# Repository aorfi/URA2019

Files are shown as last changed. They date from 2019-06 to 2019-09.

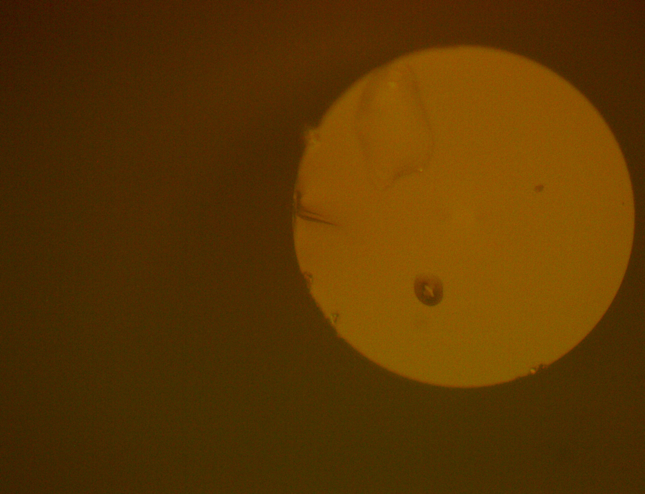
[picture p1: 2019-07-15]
Photos/CameraTest1-2.jpg

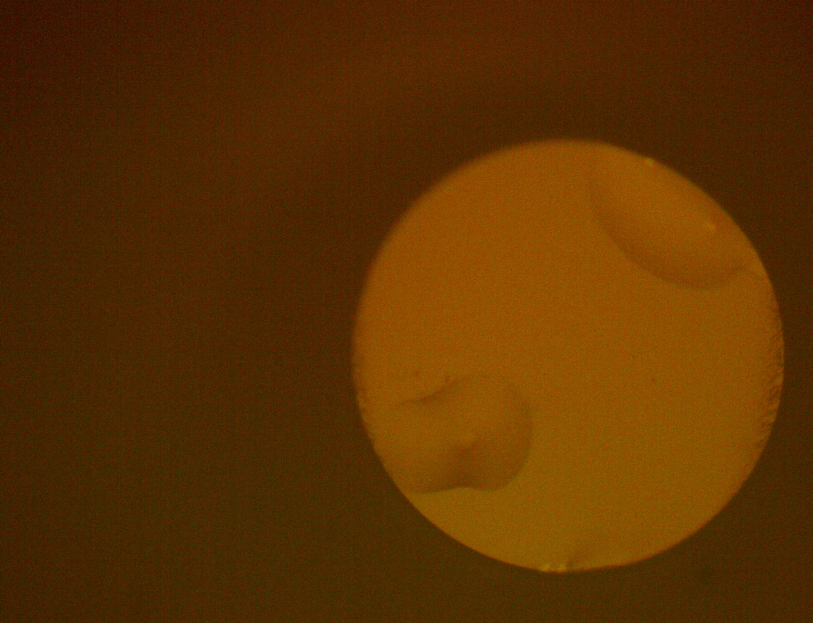
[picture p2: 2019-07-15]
Photos/CameraTest4-1.jpg

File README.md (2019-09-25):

# Undergraduate Research Assistant 

Working in Professor Bajcsy's Nano-Photonics and Quantum Optics Laboratory on the manufacturing of fiber based Fabry Perot cavities. 

## Assemblies Overview
This gives a brief explanation of each of the assemblies tested.  
### PolarizationMethod
This assembly was used to test the butt-coupling method of UV resin transfer. There were many iterations of this design, this assembly currently represents the final iteration, which was manufactured at the end of the work term.

### Camera Setup
This two camera setup was used to see the fiber alignment for the butt-coupling technique. It uses a rack and pinion design to vary the distance of the camera to the sample so that the focus can be easily found. There also exists a configuration with fixed distances, which has better structural integrity.

### RotatingCamera
This is a single USB camera mount with variable rotation. It can be used to view the reflection of the fiber in order to insure the fiber is perpendicular to the mirror. 

### ChipHolder
This simple assembly is used as a mounting feature for the fiber holder chip. It can be used to mount both the horizontal optical post as well as to sit stably on the translation stage.

## Parts Organization
Most parts were custom designed to be 3D printed, thus are stored in the CustomParts folder. Some of the later assemblies also are stored in this folder. The COTS folder stores the off the shelf items, most coming from [McMaster-Carr](https://www.mcmaster.com/) or [Thor Labs](https://www.thorlabs.com/index.cfm)

## Other
Various photos of test performed can be found in the photos folder. In addition, the slides for presentations are in the GroupMeetings folder.

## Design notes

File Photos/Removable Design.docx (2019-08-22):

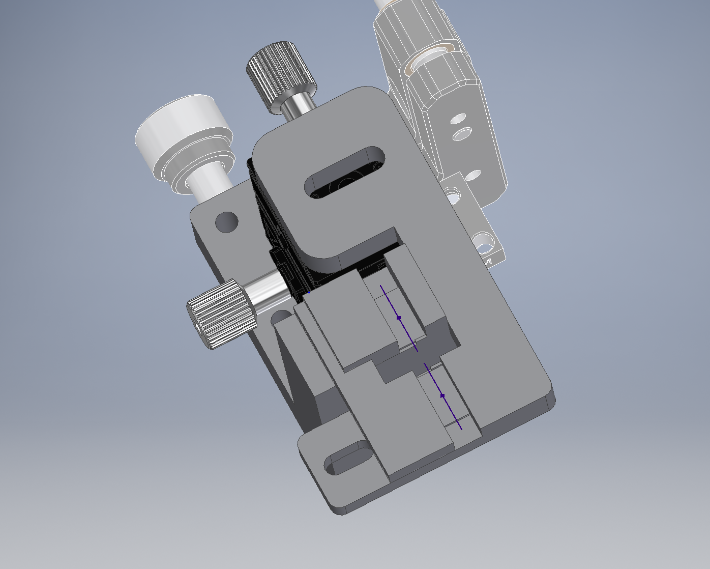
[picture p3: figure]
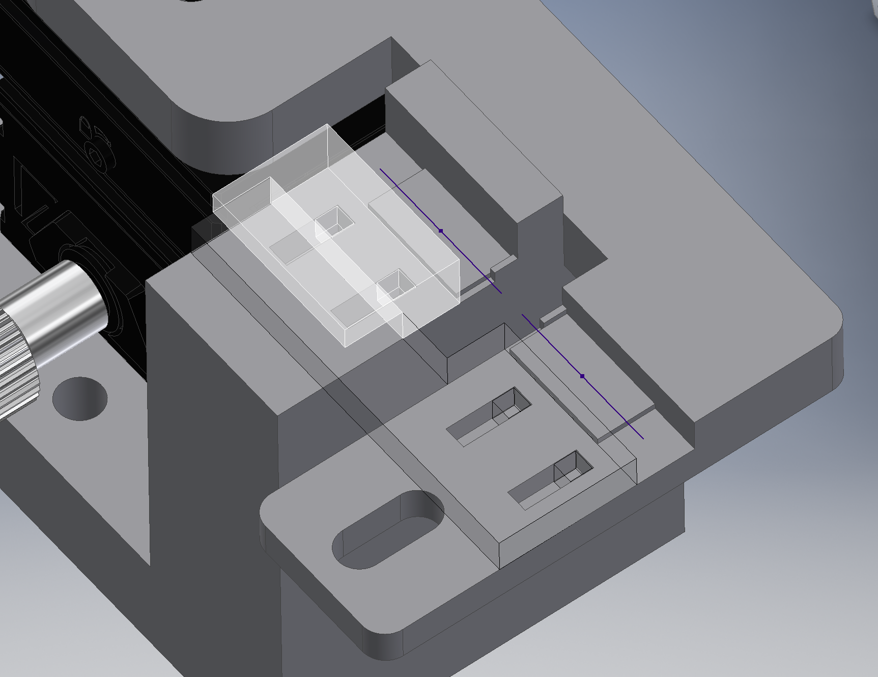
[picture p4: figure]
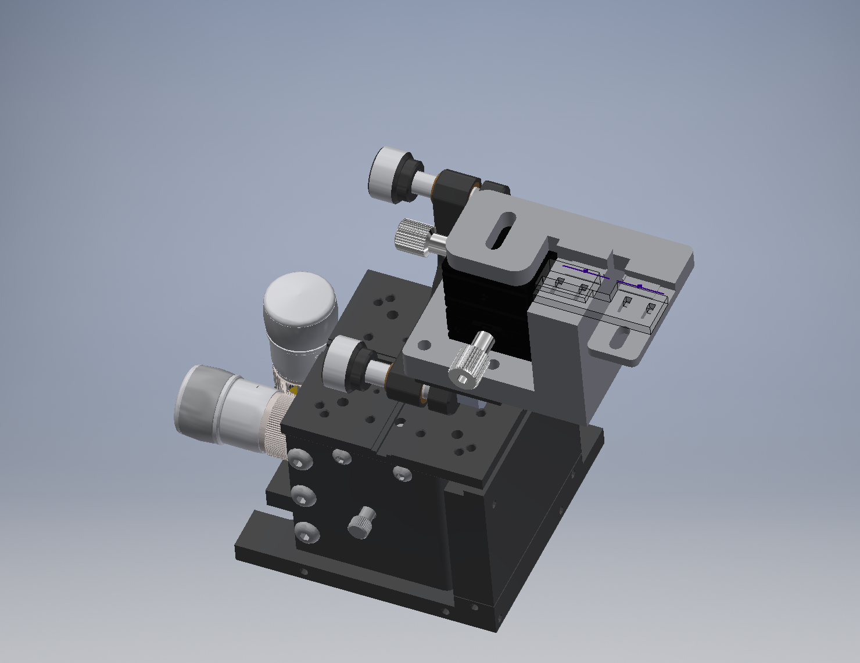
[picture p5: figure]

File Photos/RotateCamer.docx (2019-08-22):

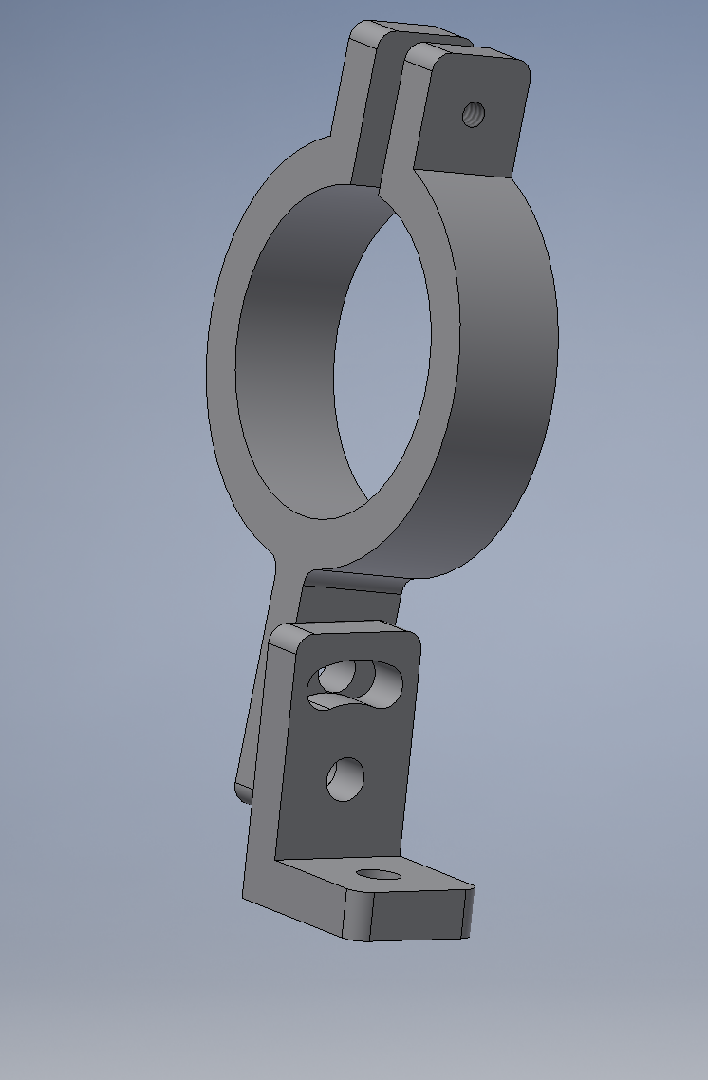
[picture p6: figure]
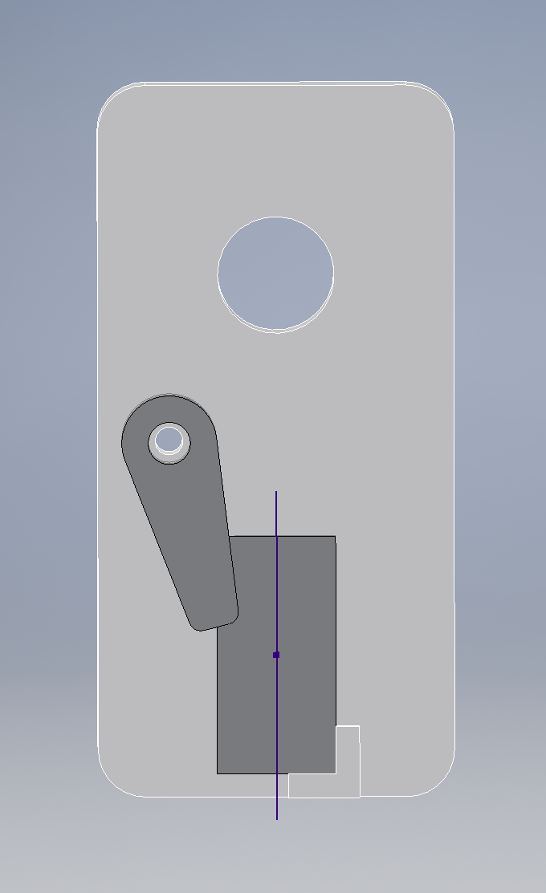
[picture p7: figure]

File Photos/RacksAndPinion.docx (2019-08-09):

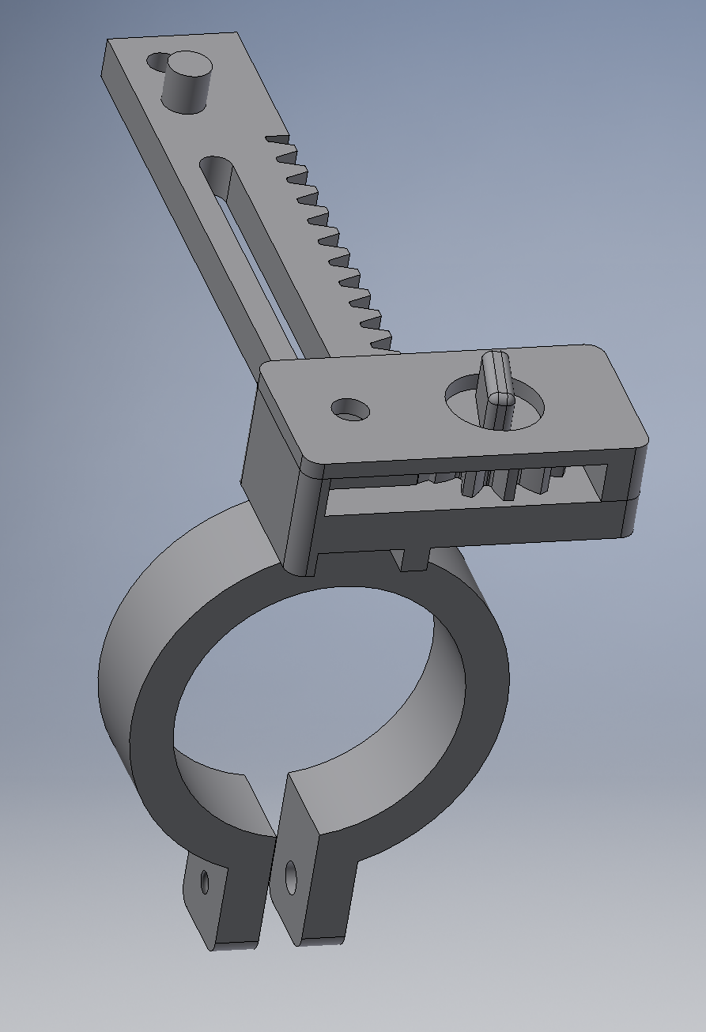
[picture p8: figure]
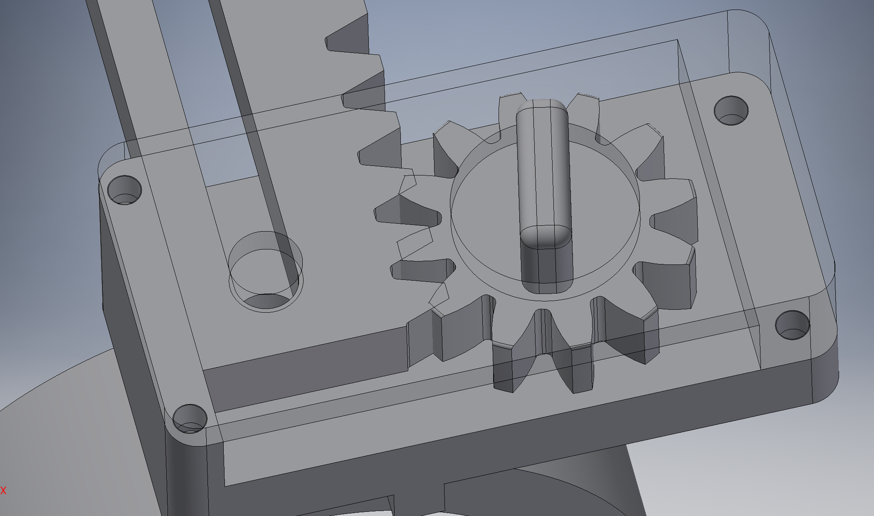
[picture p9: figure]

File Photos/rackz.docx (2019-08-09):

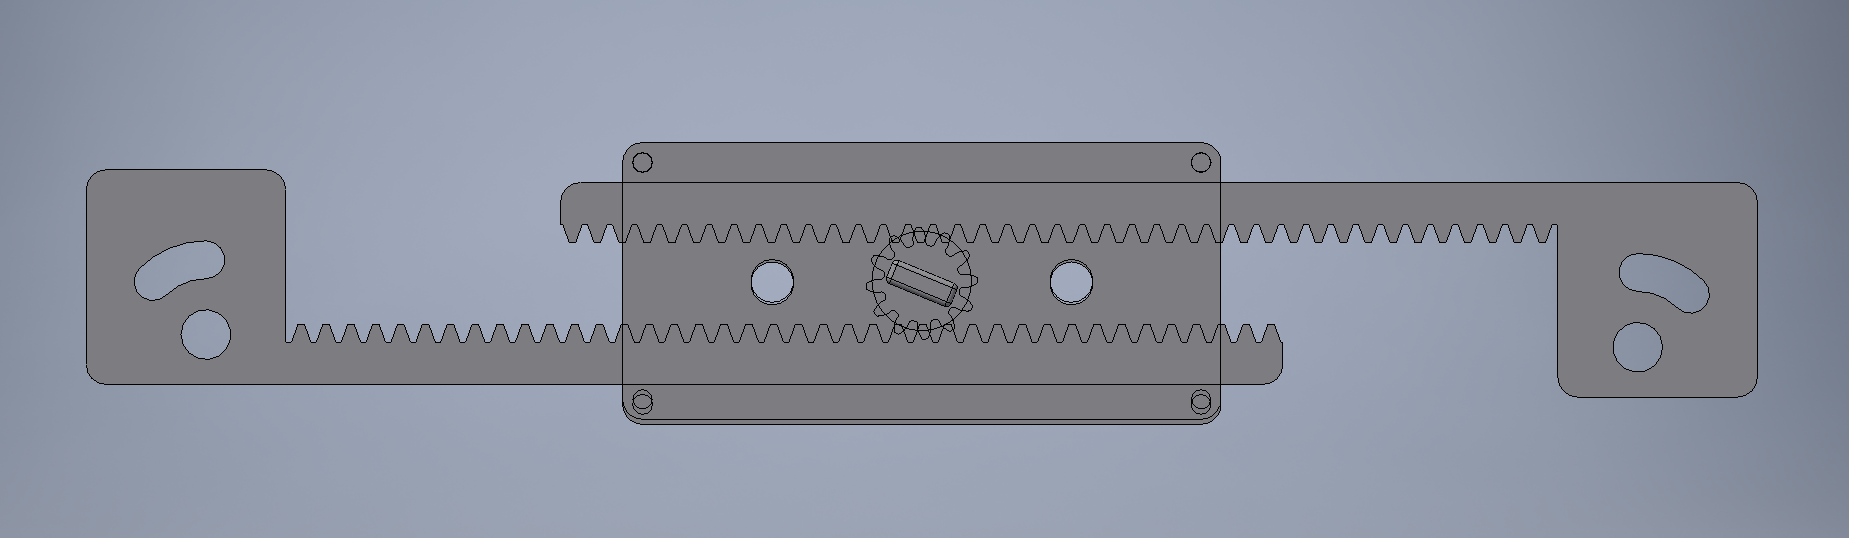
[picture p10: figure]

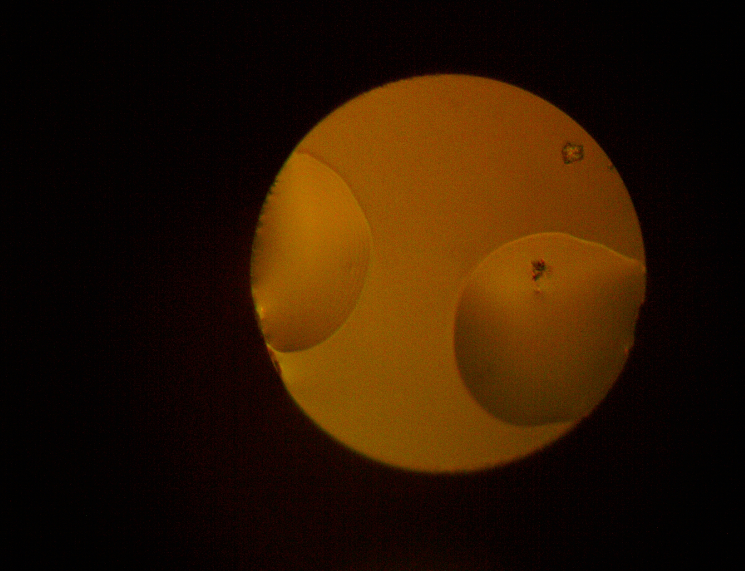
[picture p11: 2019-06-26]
Photos/RemovableDesign3-1.jpg

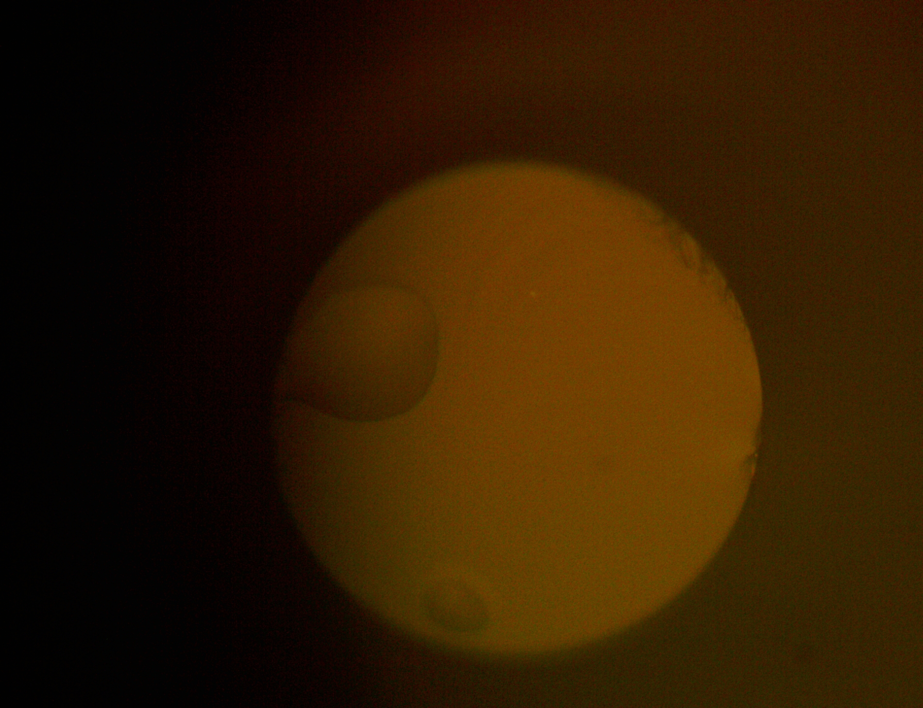
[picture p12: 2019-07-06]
Photos/RemovableDesign7-2.jpg

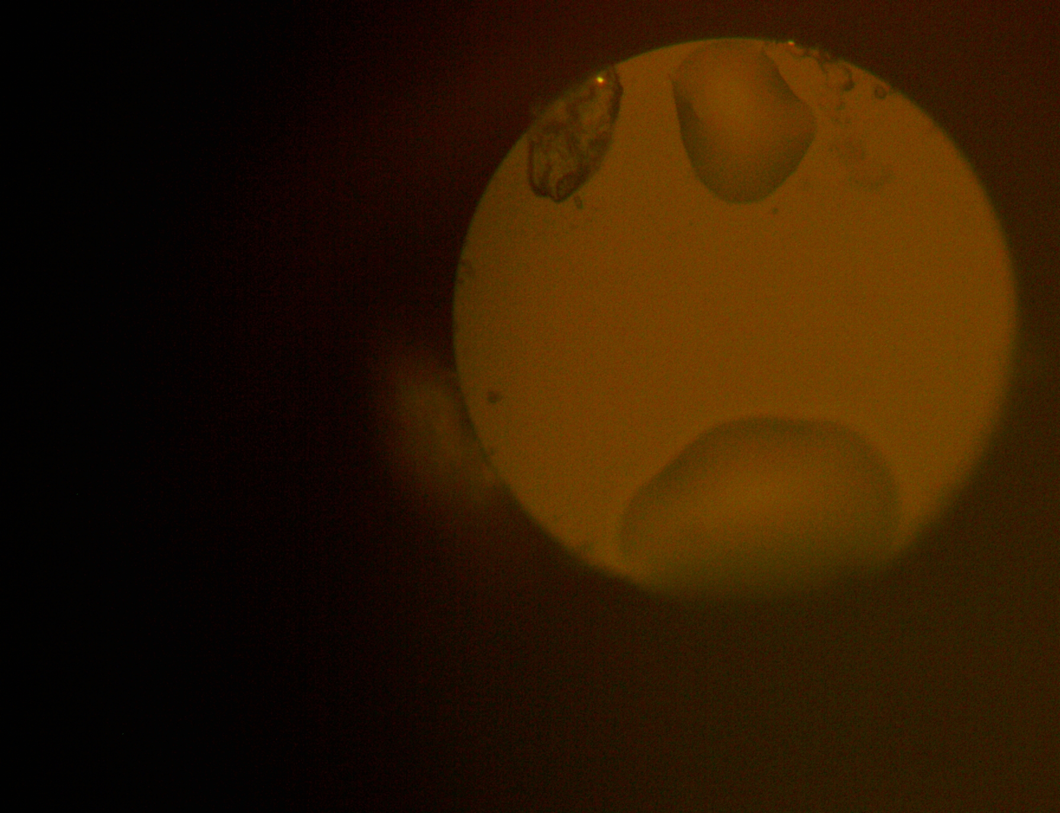
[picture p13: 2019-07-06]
Photos/RemovableDesign8-1.jpg

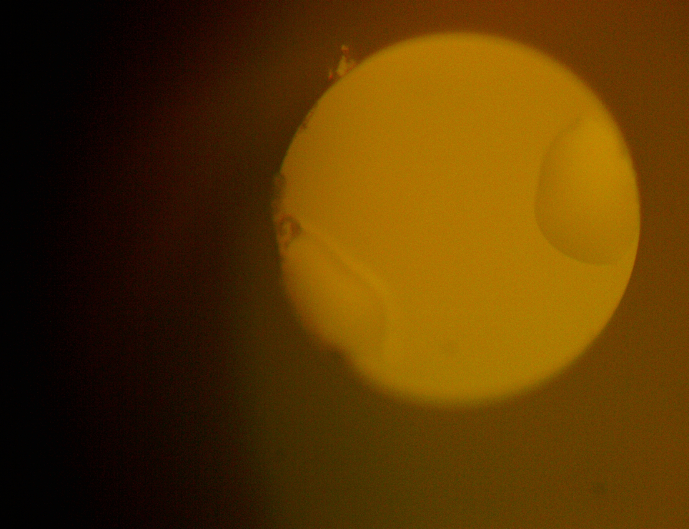
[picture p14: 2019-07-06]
Photos/RemovableDesign10-1.jpg

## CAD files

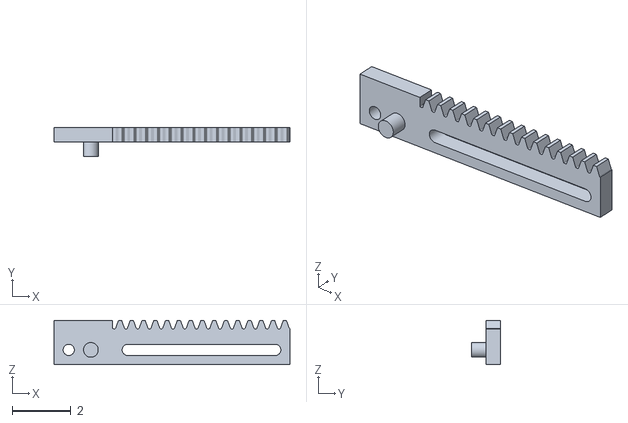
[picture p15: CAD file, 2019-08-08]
CustomParts/Rack.stl
8.00 x 1.00 x 1.50

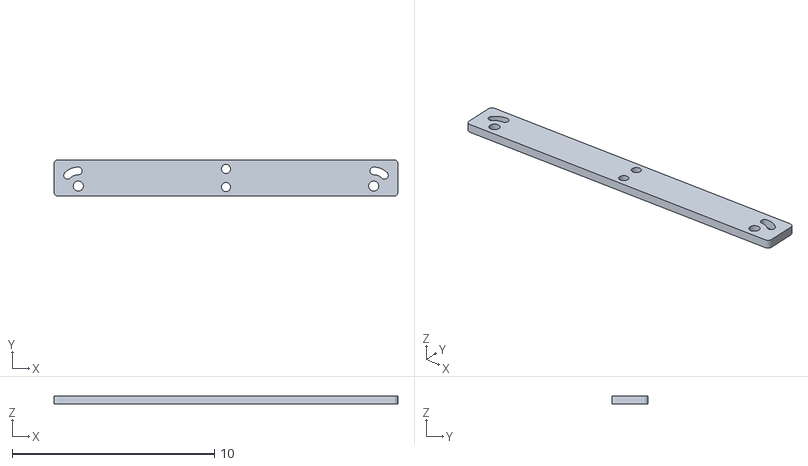
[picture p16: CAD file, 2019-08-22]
Printing/CameraBase.stl
17.0 x 1.80 x 0.4

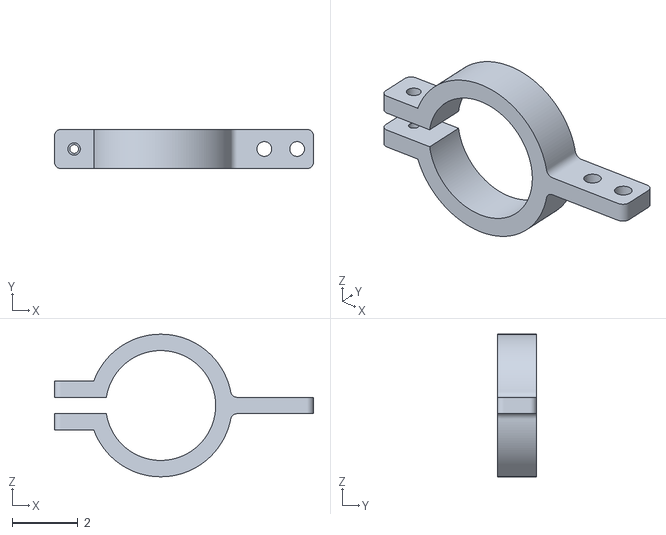
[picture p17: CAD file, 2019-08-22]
Printing/CameraClampRotate.stl
7.90 x 1.20 x 4.35

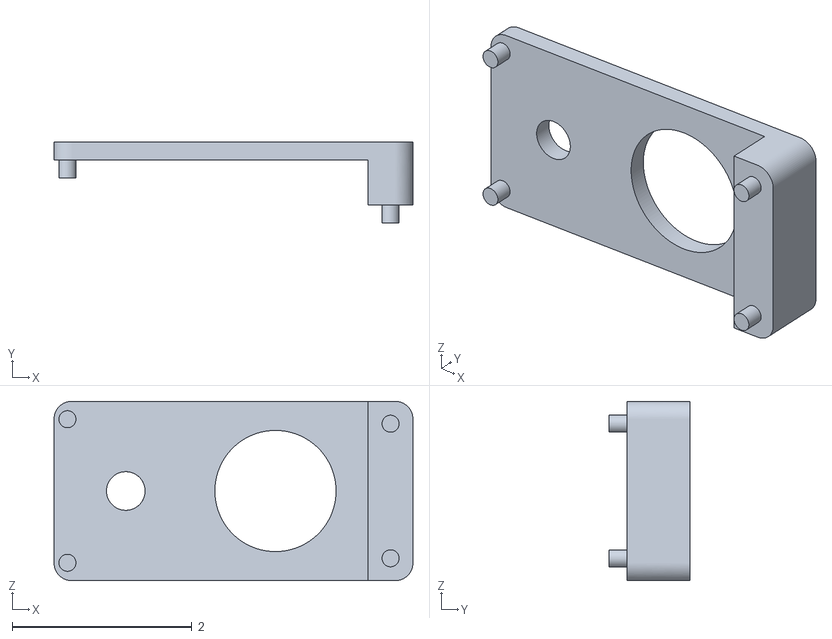
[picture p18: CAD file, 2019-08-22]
Printing/GearCover.stl
4.00 x 0.9 x 2.00

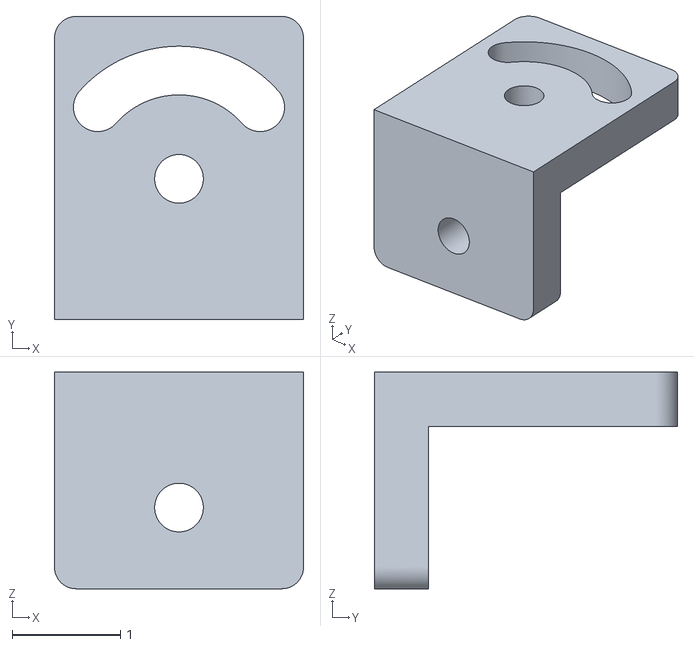
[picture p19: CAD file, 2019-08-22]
Printing/RotateLBracket.stl
2.30 x 2.80 x 2.00

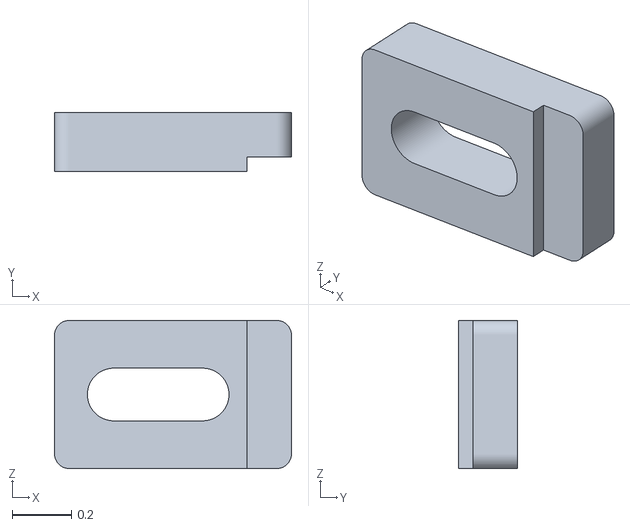
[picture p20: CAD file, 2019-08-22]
Printing/ChipClip.stl
0.8 x 0.2 x 0.5

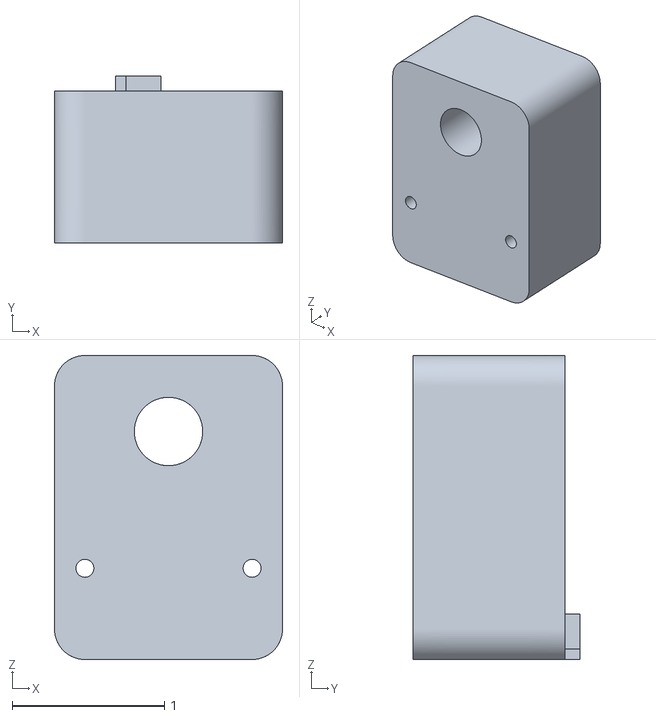
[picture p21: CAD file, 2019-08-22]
Printing/ChipHolder.stl
1.50 x 1.10 x 2.00

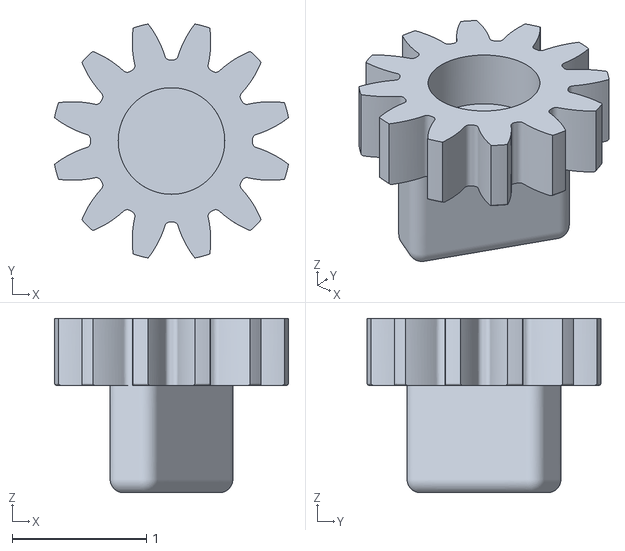
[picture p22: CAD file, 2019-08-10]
Printing/Pinion.stl
1.74 x 1.74 x 1.30

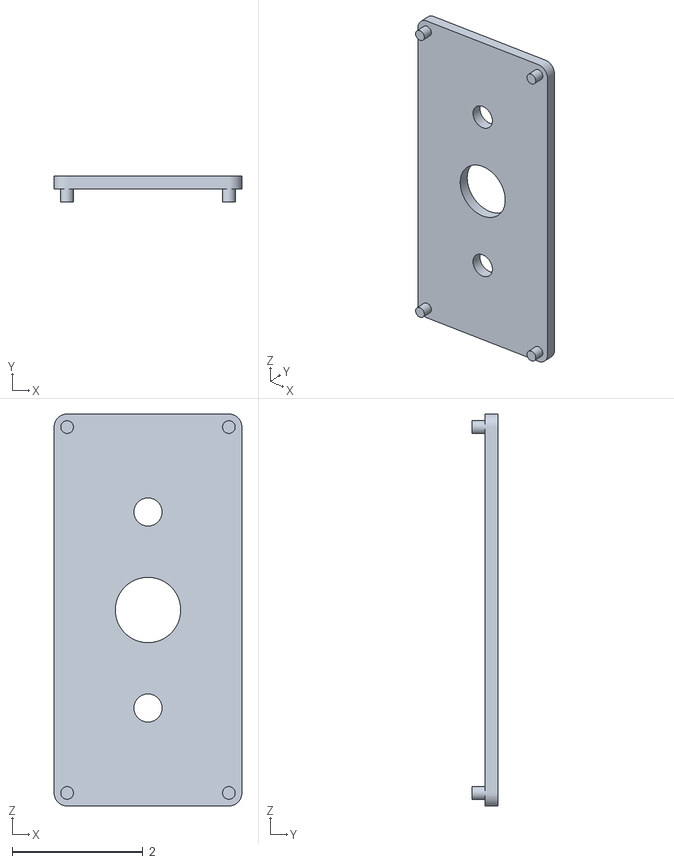
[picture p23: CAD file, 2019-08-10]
Printing/GearCoverTop.stl
2.88 x 0.4 x 6.00

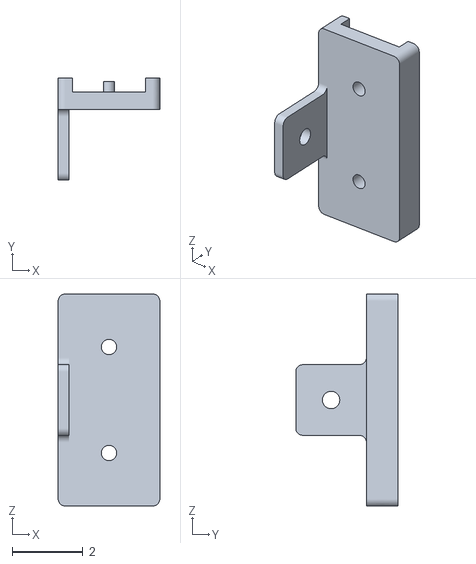
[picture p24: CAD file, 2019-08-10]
Printing/CameraLinearSupporter.stl
2.88 x 2.90 x 6.00

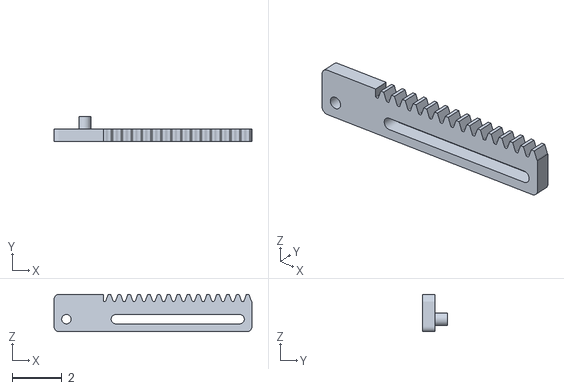
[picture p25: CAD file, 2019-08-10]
Printing/RackMirror.stl
8.00 x 1.00 x 1.50

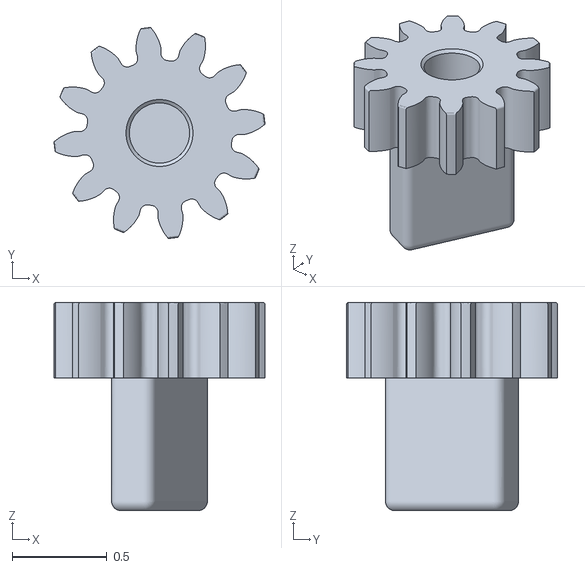
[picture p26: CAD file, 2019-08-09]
Printing/SmallPinion.stl
1.11 x 1.11 x 1.10

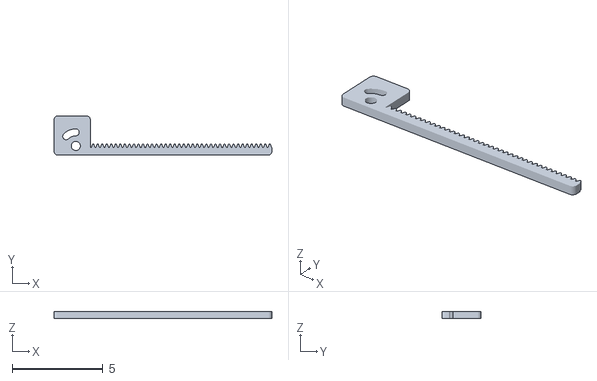
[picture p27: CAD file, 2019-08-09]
Printing/CameraBaseLeft.stl
12.0 x 2.15 x 0.4

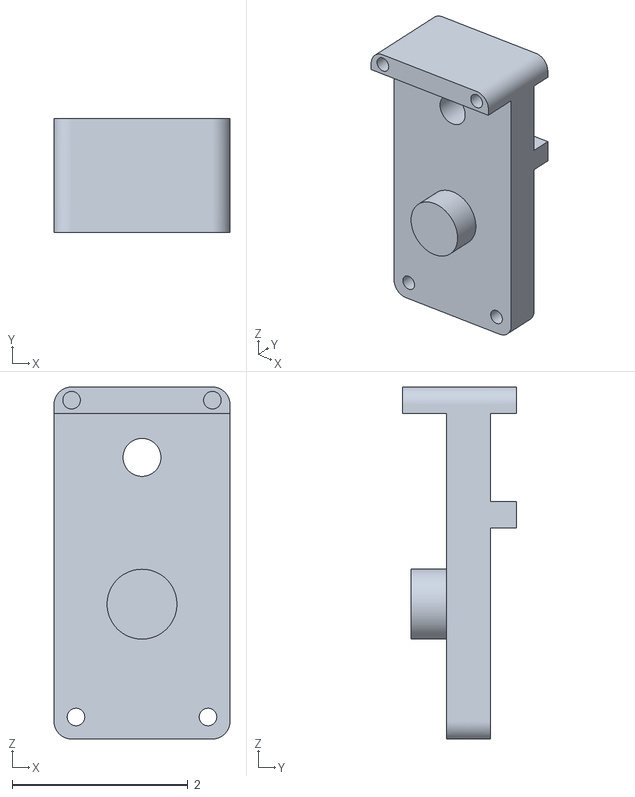
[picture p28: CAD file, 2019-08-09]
Printing/PinionHolder.stl
2.00 x 1.30 x 4.00

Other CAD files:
Printing/CameraBaseRight.stl
Printing/Nut0.375-16.stl
Printing/Pawl2.stl
Printing/PinionHolderTest.stl
COTS/BallBearing.ipt
COTS/McMaster/0.125-0.25-Shoulder91259A156.ipt
COTS/McMaster/0.125-0.3125-Shoulder91259A156.ipt
COTS/McMaster/0.125-0.375-Shoulder91259A156.ipt
COTS/McMaster/440-Nut90480A005.ipt
COTS/Newport/LinearStage-MS-125-X.ipt
COTS/ThorLabs/LinearStage-MS1S.ipt
COTS/ThorLabs/RollStage-RSP1_M.ipt
COTS/ThorLabs/YawPitchStage-KM100PM.ipt
COTS/USBCamera.ipt
CameraSetup.iam
ChipMountAssembly.iam
CustomParts/7880K140_HT-LOAD MTL GEAR--20 DEG PRESSURE ANGLE.ipt
CustomParts/AlignmentPiece.ipt
CustomParts/BaseMount.ipt
CustomParts/BearingMount.ipt
CustomParts/CameraBase.ipt
CustomParts/CameraBaseLeft.ipt
CustomParts/CameraBaseRight.ipt
CustomParts/CameraClamp.ipt
CustomParts/CameraClampRotate.ipt
CustomParts/CameraLBracket.ipt
CustomParts/CameraLinearSupporter.ipt
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

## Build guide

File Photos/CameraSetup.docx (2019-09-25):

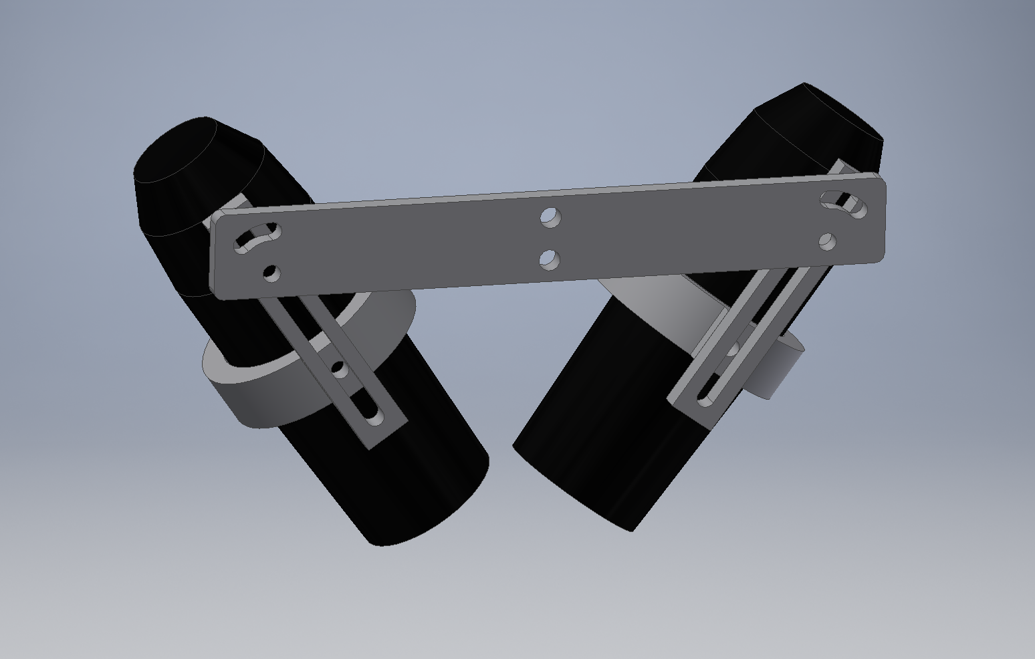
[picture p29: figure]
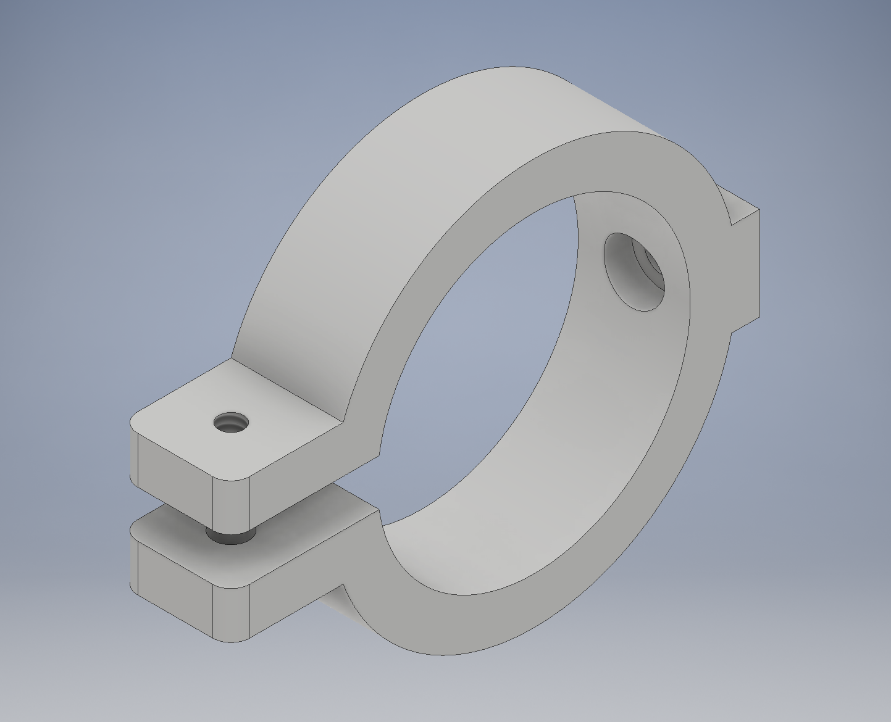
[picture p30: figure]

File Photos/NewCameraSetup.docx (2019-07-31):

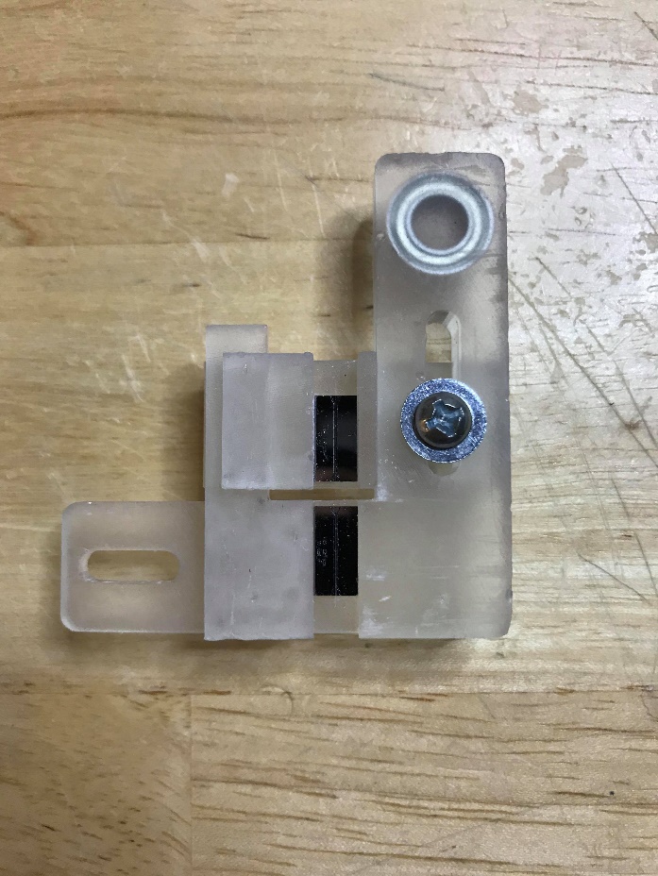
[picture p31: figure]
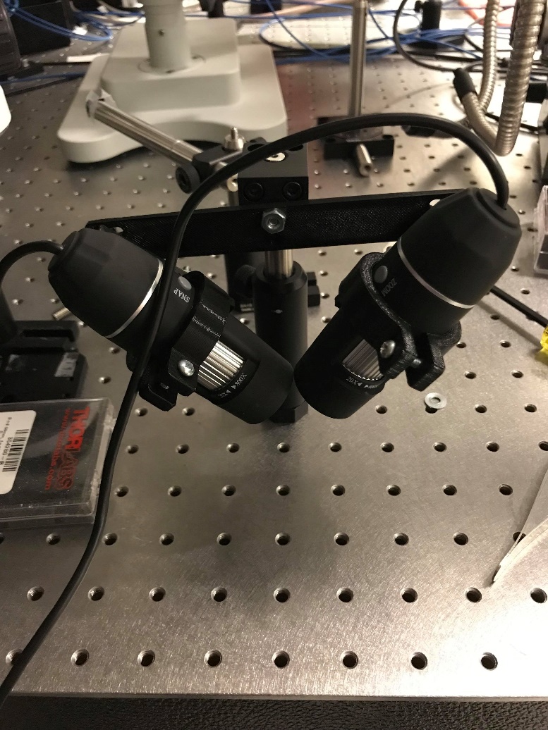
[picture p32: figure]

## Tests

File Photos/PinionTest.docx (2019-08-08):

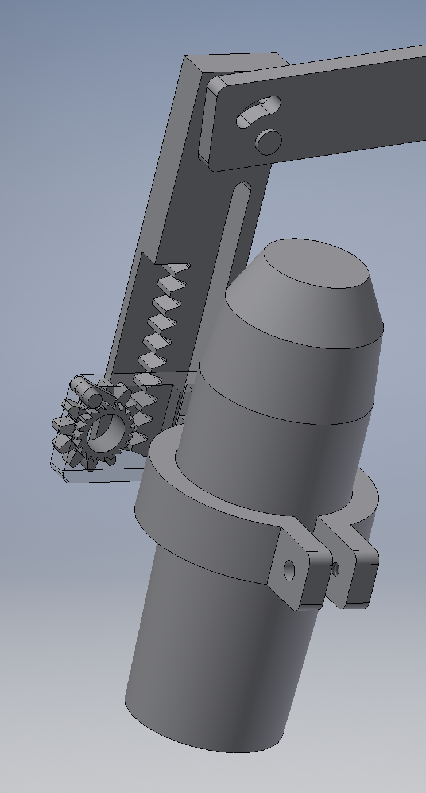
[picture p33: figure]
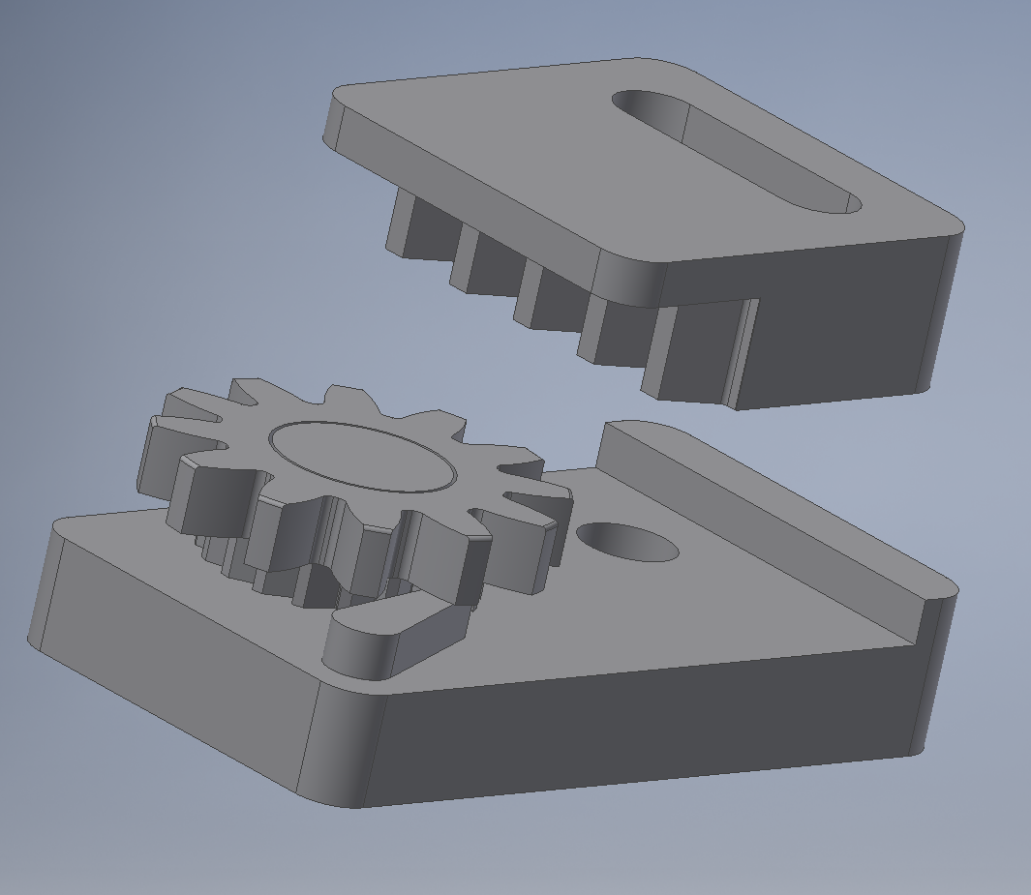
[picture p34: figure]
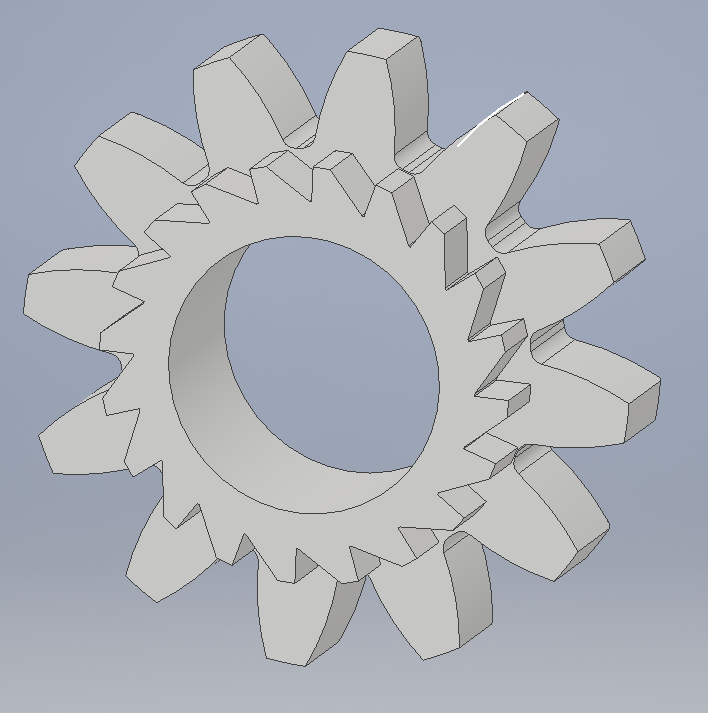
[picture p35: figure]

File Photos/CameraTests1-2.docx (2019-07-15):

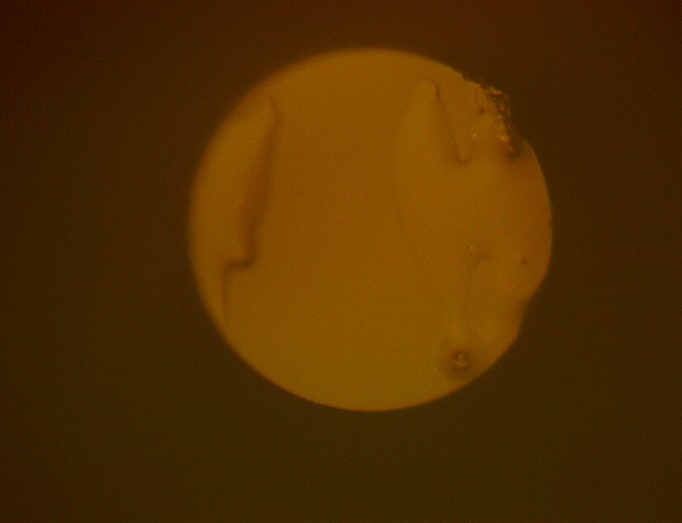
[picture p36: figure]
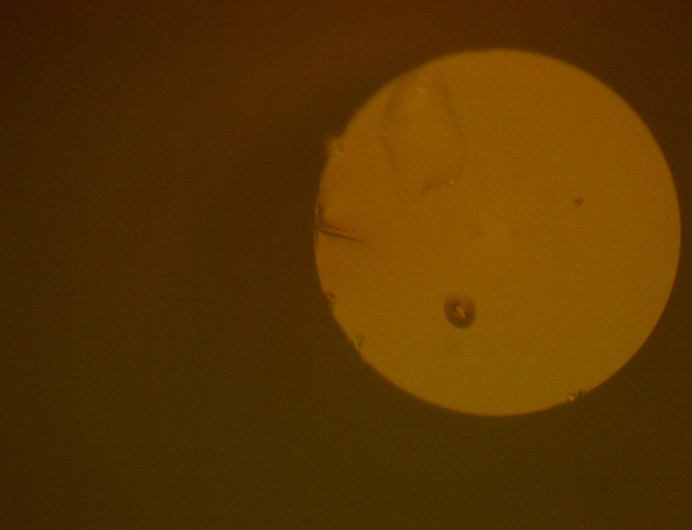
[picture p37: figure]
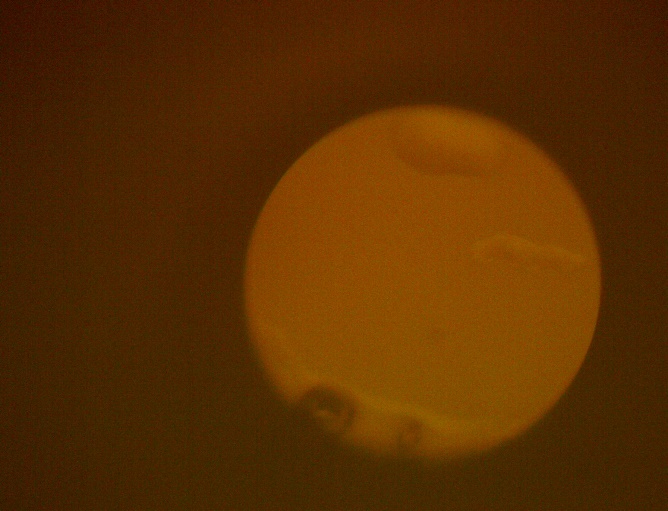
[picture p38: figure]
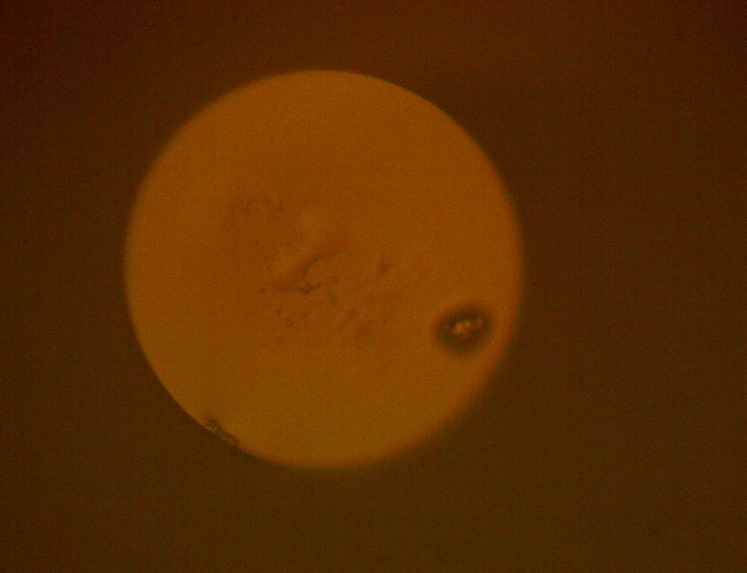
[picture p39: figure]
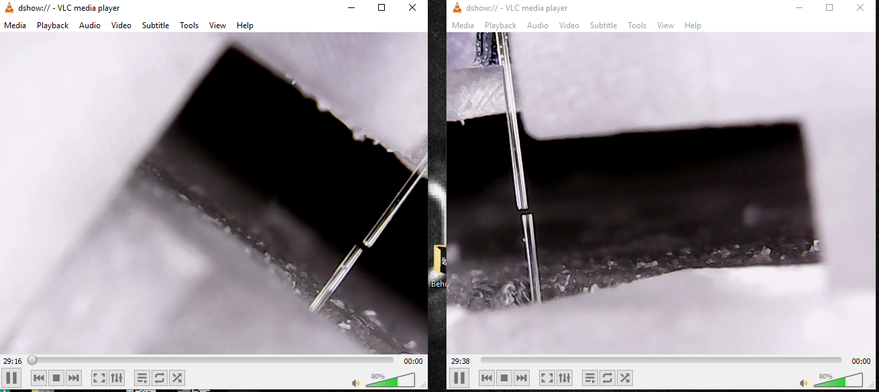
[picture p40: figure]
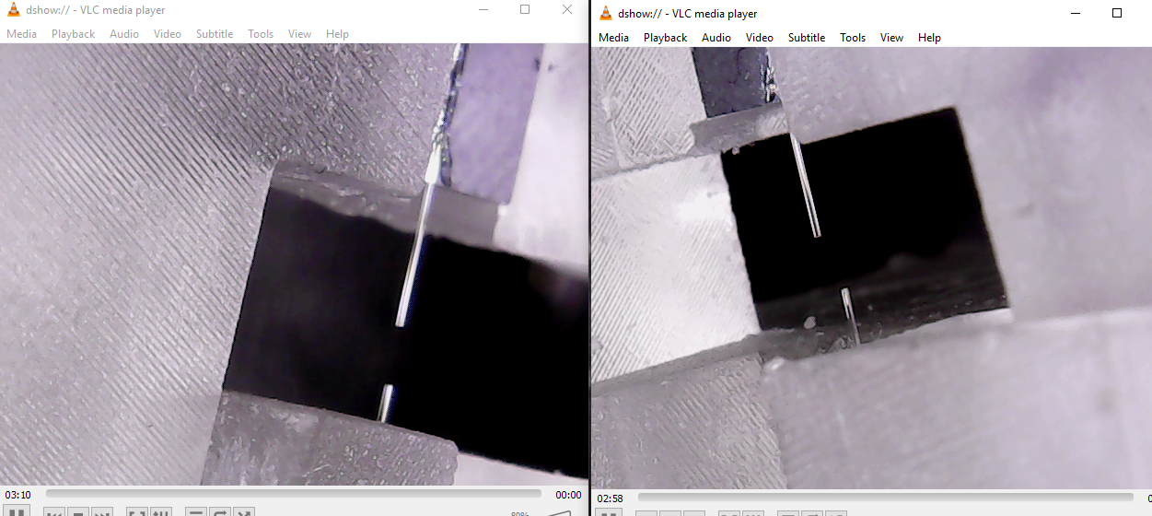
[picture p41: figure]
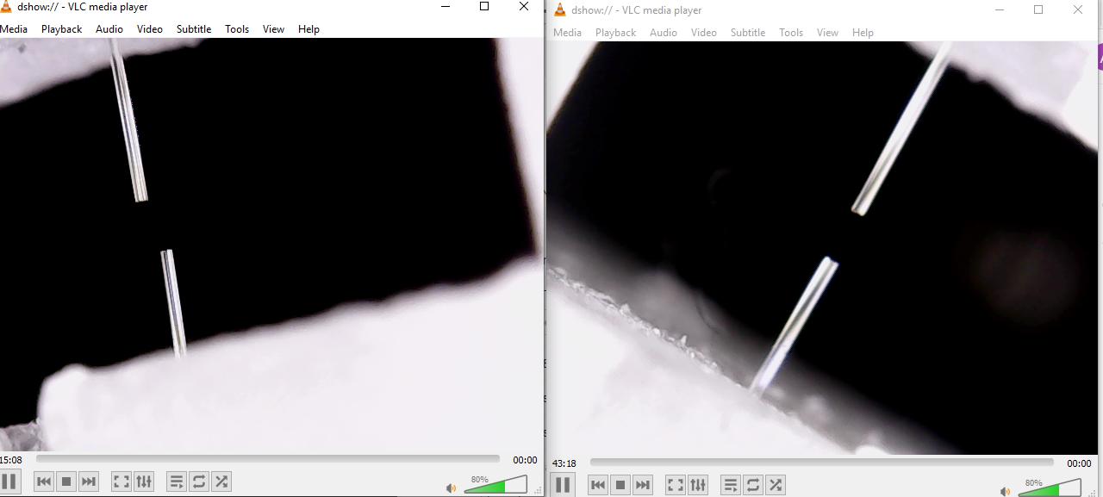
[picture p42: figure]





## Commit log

2019-06-10 Delete Old Versions
    Removing the auto saved old version folder
    [ChipMount.0005.ipt, ChipMountAssembly.0006.iam, Cover.0006.ipt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]
2019-06-10 Rotating Epoxy Transfer Rough Model
    Added a mount for the epoxy fiber which can be rotated out of the way. COTS not confirmed. Mounting points and fasteners not found.
    [ChipMount.0008.ipt, ChipMount.ipt, ChipMountAssembly.iam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]
2019-06-10 Fixed Rotating Stage
    Added gitignore
    [EpoxyFiberMountBase.ipt, PolarizationMethod.iam]
2019-06-10 Added Fasteners
    Also added photo of epoxy to fiber transfer test.
    [0.125-0.25-Shoulder91259A156.ipt, 0.125-0.3125-Shoulder91259A156.ipt, 0.125-0.375-Shoulder91259A156.ipt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]
2019-06-11 Chaged Small Linear Stage to DoveTail
    Tested adding epoxy to fiber directly with probe.
    [EpoxyFiberMountBase.ipt, PolarizationMethod.iam, RubayetChip.ipt]
2019-06-18 Butt-Coupling Tests
    Photos from these tests are added to the Photos folder. A chip pusher piece was created and prepped for printing
    [ChipPusher.ipt, ChipPusher.stl, PolarizationMethod.iam]
2019-06-20 Changed original design from a rotating stage to a removable stage for the transfer fiber. Added variable alignment pieces. Also added a chip pusher for lab testing. Please enter the commit message f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
    [AlignmentPiece.0003.ipt, AlignmentPiece.ipt, FiberMount.0010.ipt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]
2019-06-20 Removable Stage Design
    Changed original design from a rotating stage to a removable stage for
    the transfer fiber. Added variable alignment pieces. Also added a chip
    pusher for lab testing.
    Please enter the commit message for your changes. Lines starting
    [AlignmentPiece.0003.ipt, AlignmentPiece.ipt, FiberMount.0010.ipt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]
2019-06-21 Added Mounting Features
    Also altered general sizing to work with different lengths of fibers.
    Added the stl and gcode files for printing.
    [AlignmentPiece.stl, FiberMount.ipt, FiberMount.stl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]
2019-06-21 Fixed Spacing Issue
    Sliding alignment pieces were limited by slides instead of the chip.
    Also added photos for lab book.
    [AlignmentPiece.0003.ipt, AlignmentPiece.ipt, AlignmentPiece.stl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]
2019-06-25 Initial Testing of Removable Setup
    Printing files are also added.
    [PolarizationMethod.iam, RubayetChip.ipt]
2019-07-02 Test 4 and 5 of Inital Design
    Increased the slide lengths and changed slot to a hole on the fiber mount and reprinted.
    [FiberMount.stl]
2019-07-02 Changed to FiberMount
    Removed slot and replaced with hole and made slides longer. Changed position of support structures
    [FiberMount.ipt]
2019-07-06 Removable Design Tests 6-13
    Was able to get more consistant results after reprinting the removable
    stage.
    [PolarizationMethod.iam]
2019-07-15 Camera Tests 1-4
    Also photos of camera setup
2019-07-16 Created Camera Setup
    Modifying the camera setup so can get larger magnification
    [BaseMount.ipt, CameraBase.ipt, CameraClamp.ipt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]
2019-07-17 Added Mounting Point to Setup
    Hopefully this will help with the z-alignment issue. Also added the ball
    bearing to ease rotation. Added angular adjustment to camera setup.
    Powerpoint from July 16 group meeting
    [BallBearing.ipt, BaseMount.ipt, BearingMount.ipt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]
2019-07-23 Added Testing Pieces for Printer Interfacing
    Also added stls for printing and photos for lab notebook
    [BallBearing.ipt, BaseMount.0005.ipt, BaseMount.ipt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]
2019-07-31 Altered BaseMOunt for Better Printing
    Created stls for printing. Also changed CapillaryHolder for Haley.
    [BaseMount.0005.ipt, BaseMount.ipt, BaseMount.stl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]
2019-07-31 Changed Isolated System Attachment
    Instead of using the pressfit pegs and holes added a tapped hole to use
    a fastener instead. Also added lips to the FixedFiber and BearingMount
    to stop rotation
    [BaseMount.ipt, BaseMount.stl, BearingMount.ipt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]
2019-07-31 Added Lip to Stop Linear Stage Rotation
    Added stls and printing files. Also modified slider position in the
    FixedFiber so that the alignment piece sits flush with the chip
    [BaseMount.ipt, BaseMount.stl, BearingMount.stl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]
2019-08-02 Changed BaseMount Fastener to Tapped Hole
    Also printed photos
    [BaseMount.ipt, BaseMount.stl, PolarizationMethod.iam]
2019-08-06 Improvements to Camera Setup
    Two methods to improve camera setup; rack and pinion and lead screw.
    Created test pieces for each design.
    [7880K140_HT-LOAD MTL GEAR--20 DEG PRESSURE ANGLE.ipt, CameraBase.ipt, CameraSetup.iam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]
2019-08-08 Finished Rack and Pinion Camera Setup
    Also created testing assemblies to test printers capabilities.
    [CameraSetup.iam, GearCover.ipt, GearCover.stl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]
2019-08-09 Finished the Rack and Pinion Design
    Added the horizontal slider as well
    [CameraBaseLeft.ipt, CameraBaseLeft.stl, CameraBaseRight.ipt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]
2019-08-10 Changed Distance Between The Pinion and Rack
    Also added printed parts
    [CameraLinearSupporter.ipt, CameraLinearSupporter.stl, CameraSetup.iam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]
2019-08-22 Created Camera Mount and Chip Holder
    [CameraBase.ipt, CameraBase.stl, CameraClampRotate.ipt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]
2019-09-25 Final Presentation Made
    [CameraSetup.iam]
2019-09-25 General Organization
    Also started to write better readme
    [CameraSetup.iam, PolarizationMethod.iam]
2019-09-25 README Update
    Started to make overview of assemblies
    [PolarizationMethod.iam]
2019-09-25 Finished README
    Made sure parts were all visible in the assemblies
    [RotatingCamera.iam]
